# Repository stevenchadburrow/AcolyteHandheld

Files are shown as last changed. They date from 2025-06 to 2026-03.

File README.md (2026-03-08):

# Acolyte Handheld

The Acolyte Handheld is a portable PIC32MZ based game console, an revision of <a href="https://github.com/stevenchadburrow/AcolyteHandPICd32">my previous project</a>.  It is programmed with my own homebrew <a href="https://github.com/stevenchadburrow/PICnes">PICnes Emulator</a>, as well as the <a href="https://github.com/deltabeard/Peanut-GB">Peanut-GB Emulator</a> and the <a href="https://github.com/ITotalJustice/TotalSMS">TotalSMS Emulator</a>.  

<b>Features</b>

<ul>
  <li>Runs on a battery and is charged by a USB-C cable.</li>
  <li>Switchable between VGA and LCD displays without needing to reboot.</li>
  <li>Supports four players simultaneously through the use of additional controllers.</li>
  <li>The built-in NES emulator has been tested with over 120+ games at this point, including but not limited to the list <a href="https://github.com/stevenchadburrow/AcolyteHandPICd32/tree/main/NES">here</a>.  As a benchmark, Super Mario Bros 3 currently runs full speed at 30 FPS.  My demo video of Super Mario Bros 3 can be found <a href="https://www.youtube.com/watch?v=WGrEMQLWrP4">here</a>.</li>
  <li>The imported GB/GBC emulator is very accurate and runs games at full speed.</li>
  <li>The imported SMS/GG/SG emulator is very accurate and runs games at full speed.</li>
  <li>Built-in WAV audio player for listening to music.</li>
  <li>Custom built 3D printed enclosure and buttons.</li>
</ul>

<b>Specifications</b>

Microchip PIC32MZ2048EFH144 running at 300 MHz (overclocked)<br>
Internal memory of 512KB of RAM and 2MB of Flash ROM<br>
Added 4MB external SQI Flash ROM for GBC support<br>

<b>Video</b>

VGA 1024x768 resolution at 70 Hz with 256 colors or 65K colors<br>
ILI9341 LCD 320x240 resolution with 65K colors<br>
Effective resolution of NES emulator at 256x240, 3x integer scaled on VGA<br>
Effective resolution of GB/GBC/GG emulator at 160x144, 3x integer scaled on VGA<br>
Effective resolution of SMS/SG emulator at 256x192, 3x integer scaled on VGA<br>

<b>Audio</b>

Dual 6-bit audio channels<br>
Headphone jack and internal speaker<br>

<b>HID</b>

2x Sega Genesis controller ports<br>
USB port for keyboard, mouse, or Xbox-360 type controller<br>
14 mappable buttons on device<br>

<b>File System</b>

Elm-Chan's <a href="https://elm-chan.org/fsw/ff/">FatFS Generic FAT Filesystem Module</a> for Micro TF Cards<br>
(use command 'sudo mkfs.vfat /dev/sdX' to format card)<br>

<b>UART</b>

FT232RL USB-to-UART adapter<br>
(use command 'sudo picocom /dev/ttyUSB0' for default 9600 baud connection)<br>

<b>NES Emulator</b>

My own homebrew NES Emulator called <a href="my own homebrew NES emulator">PICnes</a>, supporting NROM, UxROM, CxROM, AxROM, MMC1, and MMC3 mappers<br>
Programmed with speed over accuracy in mind, runs most games at full speed without alteration<br>
Supports settings adjustments, game save files, and save-states<br>

<b>GB/GBC Emulator</b>

Mahyar Koshkouei's <a href="https://github.com/deltabeard/Peanut-GB">Peanut-GB (with MiniGB-APU) Emulator</a><br>
Copied and edited from the <a href="https://github.com/froggestspirit/Peanut-GB/">Version by "froggestspirit"</a> for GBC support<br>
Supports 1.5x scaling, DMG/GBC palettes, and game save files<br>

<b>SMS/GG/SG Emulator</b>

ITotalJustice's <a href="https://github.com/ITotalJustice/TotalSMS">TotalSMS Emulator</a><br>
Supports SMS / GG / SB games on same emulator, with game save files<br>

<b>WAV Audio Player</b>

Plays all tested .wav files with 1 or 2 channels, using 8 or 16 bits, and at any sample rate.<br>
(use 'ffmpeg' or 'sox' to convert your favorite .mp3 files to .wav format)<br>

<b>Links</b>

<a href="http://forum.6502.org/">http://forum.6502.org/</a> for the 6502 Forum, an incredible resource for everything 6502 related.<br>
<a href="https://www.nesdev.org/wiki/Nesdev_Wiki">https://www.nesdev.org/wiki/Nesdev_Wiki</a> for the very best NES programming guidance.<br> 
<a href="https://www.aidanmocke.com/">https://www.aidanmocke.com/</a> for a bunch of PIC32MZ projects (without Harmony), including USB.<br>
<a href="http://elm-chan.org/">http://elm-chan.org/</a> for a bunch of projects, including MMC (aka TF Card) and FatFs.<br>
<a href="https://github.com/deltabeard/">https://github.com/deltabeard/</a> for a bunch of projects, including Peanut-GB and MiniGB-APU projects.<br>
<a href="https://github.com/froggestspirit/">https://github.com/froggestspirit/</a> for a bunch of projects, including the GBC version of Peanut-GB.<br>
<a href="https://github.com/ITotalJustice/">https://github.com/ITotalJustice/</a> for a bunch of projects, including TotalSMS and other emulators.<br>
<a href="https://github.com/bfirsh/jsnes/tree/master/roms/lj65">https://github.com/bfirsh/jsnes/tree/master/roms/lj65</a> for LJ65 download and license (ROM in source).<br>
<a href="https://hackaday.com/2025/06/19/game-boy-nes-why-not-both/">https://hackaday.com/2025/06/19/game-boy-nes-why-not-both/</a> for the Hack-A-Day article!<br>

<b>Pictures</b>

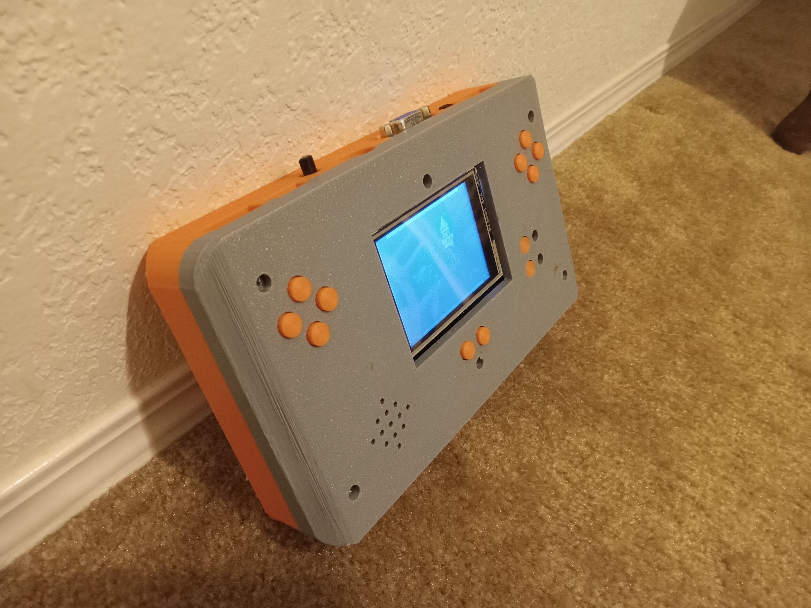
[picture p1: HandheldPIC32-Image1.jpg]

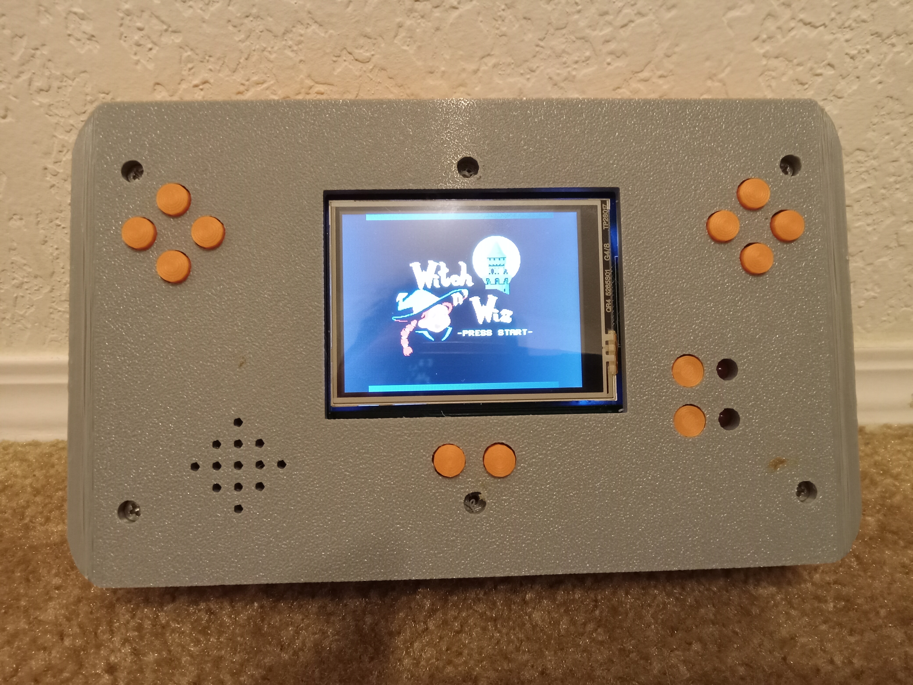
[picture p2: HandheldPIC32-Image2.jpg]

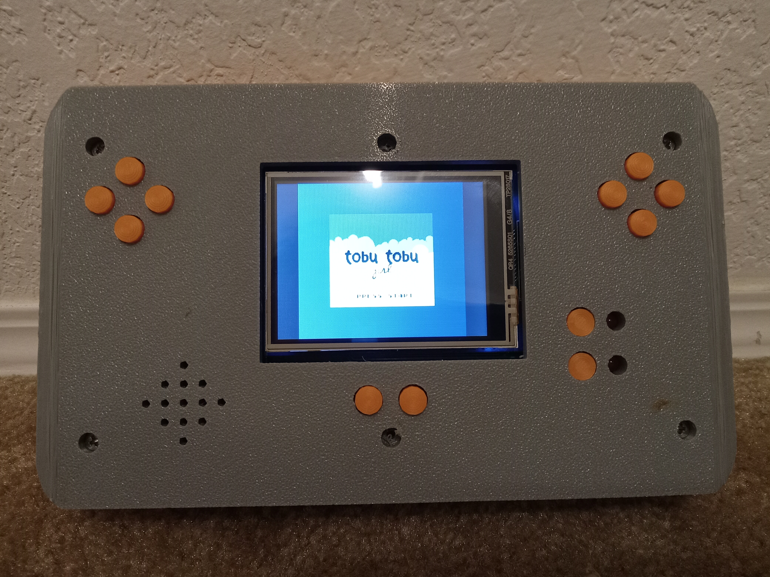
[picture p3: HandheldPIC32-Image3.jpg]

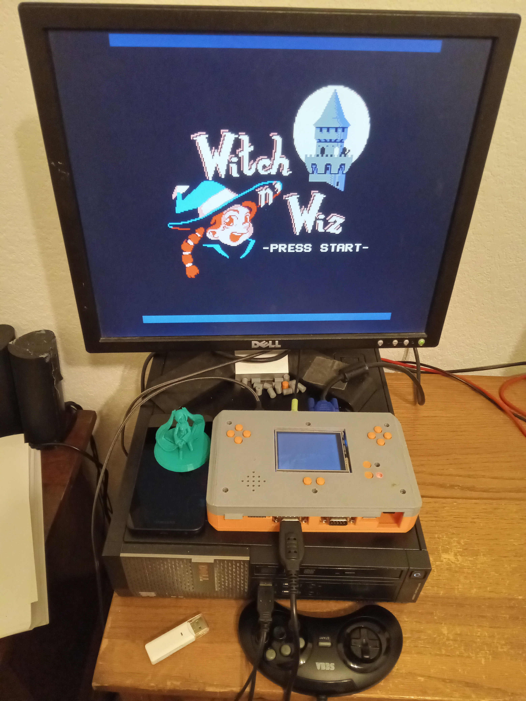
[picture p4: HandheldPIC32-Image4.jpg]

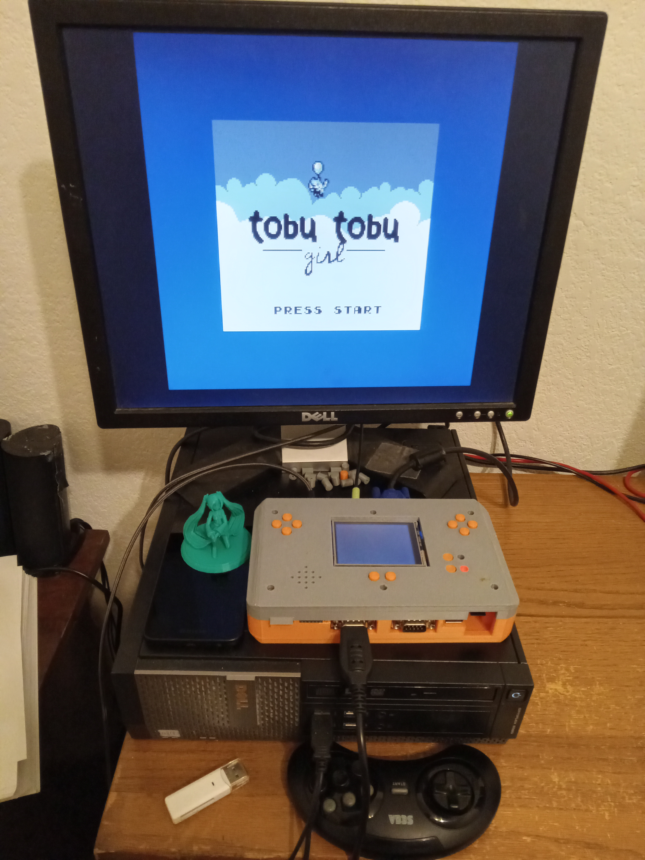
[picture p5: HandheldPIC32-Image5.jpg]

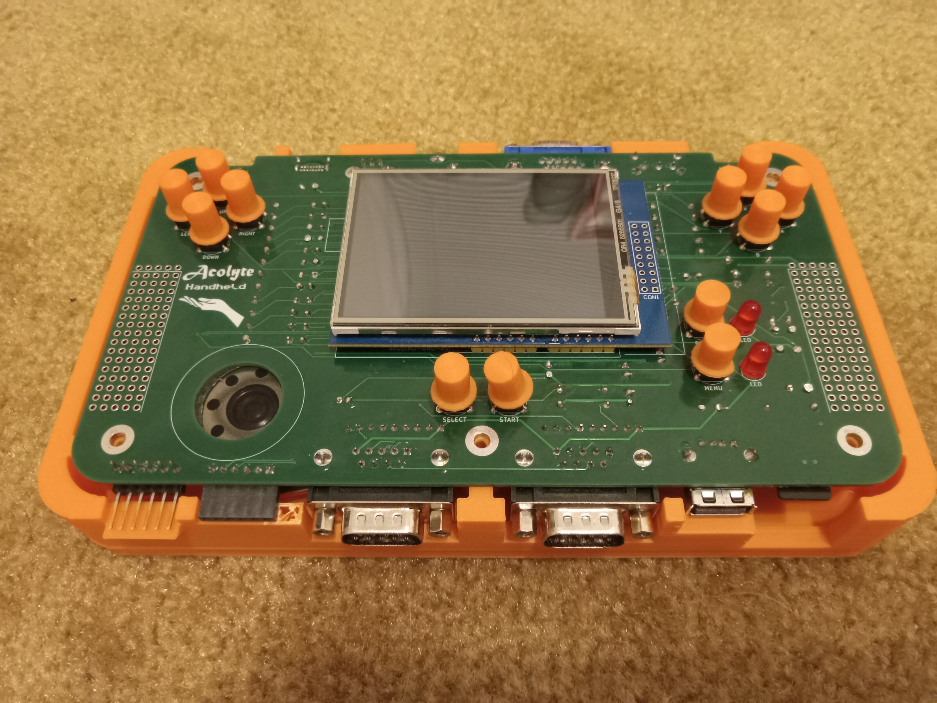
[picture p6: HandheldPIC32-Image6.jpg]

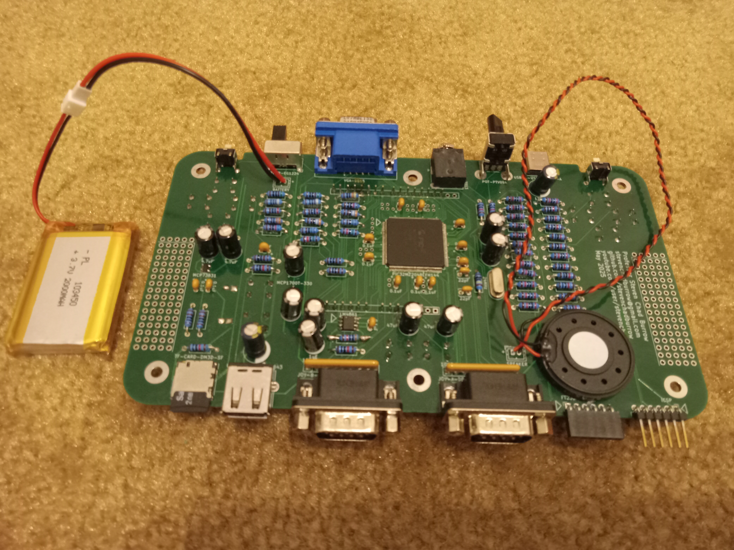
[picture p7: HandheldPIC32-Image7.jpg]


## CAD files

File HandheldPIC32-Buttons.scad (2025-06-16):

// typical buttons
translate([-10,0,0])
{
    difference()
    {
        intersection()
        {
            union()
            {
                cylinder(11,3.75,3.75,center=false);
                cylinder(0.75,5,5,center=false);
            }
            sphere(11);
        }
        cube([2.85,2.85,7],center=true);
       
    }
}

// reset and menu buttons
translate([10,0,0])
{
    difference()
    {
        difference()
        {
            union()
            {
                cylinder(9,3.75,3.75,center=false);
                difference()
                {
                    cylinder(0.75,5,5,center=false);
                    translate([3.75,-5,-1])
                    {
                        cube([10, 10, 10], center = false);
                    }
                }
            }
            translate([0,0,20])
            {
                sphere(12);
            }
        }
        cube([2.85,2.85,7],center=true);
       
    }
}

// no shoulder buttons yet!

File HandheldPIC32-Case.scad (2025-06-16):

h = 40; // total height of case
c = 15; // top height of the case

difference()
{
    translate([0, 0, c-h])
    {
        difference()
        {
            union()
            {
                // outside of case, good
                intersection()
                {
                    translate([-85, 45, 0])
                    { 
                        cylinder(h, 12, 12, center=false);
                    }
                    translate([-85, -57, h/2])
                    {
                        rotate([-90, 0, 0])
                        {
                            cylinder(114, h/2, h/2, center=false);
                        }
                    }
                }
                intersection()
                {
                    translate([-85, -45, 0])
                    { 
                        cylinder(h, 12, 12, center=false);
                    }
                    translate([-85, -57, h/2])
                    {
                        rotate([-90, 0, 0])
                        {
                            cylinder(114, h/2, h/2, center=false);
                        }
                    }
                }
                intersection()
                {
                    translate([85, 45, 0])
                    { 
                        cylinder(h, 12, 12, center=false);
                    }
                    translate([85, -57, h/2])
                    {
                        rotate([-90, 0, 0])
                        {
                            cylinder(114, h/2, h/2, center=false);
                        }
                    }
                }
                intersection()
                {
                    translate([85, -45, 0])
                    { 
                        cylinder(h, 12, 12, center=false);
                    }
                    translate([85, -57, h/2])
                    {
                        rotate([-90, 0, 0])
                        {
                            cylinder(114, h/2, h/2, center=false);
                        }
                    }
                }
                translate([-87, -57, 0])
                {
                    cube([174, 114, h], center=false);
                }
                intersection()
                {
                    translate([-97, -47, 0])
                    { 
                        cube([14, 94, h], center=false);
                    }
                    translate([-85, -55, h/2])
                    {
                        rotate([-90, 0, 0])
                        {
                            cylinder(114, h/2, h/2, center=false);
                        }
                    }
                }
                intersection()
                {
                    translate([83, -47, 0])
                    { 
                        cube([14, 94, h], center=false);
                    }
                    translate([85, -55, h/2])
                    {
                        rotate([-90, 0, 0])
                        {
                            cylinder(114, h/2, h/2, center=false);
                        }
                    }
                }
                difference() // programming pin protector, added
                {
                    translate([-80, -55, h-c-8.5])
                    {
                        rotate([45,0,0])
                        {
                            cube([16, 10, 10], center=false);
                        }
                    }
                    translate([-81, -100-40, h-c-3])
                    {
                        cube([18, 100, 3], center=false);
                    }
                }
            }
            union()
            {
                // inside of case, good
                translate([-80, 40, 5])
                { 
                    cylinder(h-10, 12, 12, center=false);
                }
                translate([-80, -40, 5])
                { 
                    cylinder(h-10, 12, 12, center=false);
                }
                translate([80, 40, 5])
                { 
                    cylinder(h-10, 12, 12, center=false);
                }
                translate([80, -40, 5])
                { 
                    cylinder(h-10, 12, 12, center=false);
                }
                translate([-82, -52, 5])
                {
                    cube([164, 104, h-10], center=false);
                }
                translate([-92, -42, 5])
                {
                    cube([14, 84, h-10], center=false);
                }
                translate([78, -42, 5])
                {
                    cube([14, 84, h-10], center=false);
                }
                
                // screw holes, good
                translate([-80, 40, h-5])
                {
                    cylinder(20, 3, 3, center=false);
                }
                translate([-80, -40, h-5])
                {
                    cylinder(20, 3, 3, center=false);
                }
                translate([0, 40, h-5])
                {
                    cylinder(20, 3, 3, center=false);
                }
                translate([0, -40, h-5])
                {
                    cylinder(20, 3, 3, center=false);
                }
                translate([80, 40, h-5])
                {
                    cylinder(20, 3, 3, center=false);
                }
                translate([80, -40, h-5])
                {
                    cylinder(20, 3, 3, center=false);
                }
                
                // button holes, good
                translate([-70, 33, h-c])
                {
                    cylinder(100, 4.25, 4.25, center=false);
                }
                translate([-78, 25, h-c])
                {
                    cylinder(100, 4.25, 4.25, center=false);
                }
                translate([-70, 17, h-c])
                {
                    cylinder(100, 4.25, 4.25, center=false);
                }
                translate([-62, 25, h-c])
                {
                    cylinder(100, 4.25, 4.25, center=false);
                }
                translate([70, 33, h-c])
                {
                    cylinder(100, 4.25, 4.25, center=false);
                }
                translate([78, 25, h-c])
                {
                    cylinder(100, 4.25, 4.25, center=false);
                }
                translate([70, 17, h-c])
                {
                    cylinder(100, 4.25, 4.25, center=false);
                }
                translate([62, 25, h-c])
                {
                    cylinder(100, 4.25, 4.25, center=false);
                }
                translate([-6, -30, h-c])
                {
                    cylinder(100, 4.25, 4.25, center=false);
                }
                translate([6, -30, h-c])
                {
                    cylinder(100, 4.25, 4.25, center=false);
                }
                translate([52, -10, h-c])
                {
                    cylinder(100, 4.25, 4.25, center=false);
                }
                translate([52, -22, h-c])
                {
                    cylinder(100, 4.25, 4.25, center=false);
                }
                
                // led holes, good
                translate([61.735, -10, h-c])
                {
                    cylinder(100, 3, 3, center=false);
                }
                translate([61.735, -22, h-c])
                {
                    cylinder(100, 3, 3, center=false);
                }
                
                // shoulder button holes, fixed
                translate([-75, 39.25, h-c-9])
                {
                    cube([10, 7.5, 10], center=false);
                }
                translate([-70-10, 39.25, h-c-9])
                {
                    cube([20, 20, c-5], center=false);
                }
                translate([65, 39.25, h-c-9])
                {
                    cube([10, 7.5, 10], center=false);
                }
                translate([70-10, 39.25, h-c-9])
                {
                    cube([20, 20, c-5], center=false);
                }
                
                // screen hole, fixed
                translate([-35, -20, h-c])
                {
                    cube([72, 55, 100], center=false);
                }
                
                // speaker holes, good
                translate([-55, -30, h-c])
                {
                    cylinder(7.5, 15, 15, center=false);
                    cylinder(100, 1.5, 1.5, center=false);
                }
                translate([-60, -30, h-c])
                {
                    cylinder(100, 1.5, 1.5, center=false);
                }
                translate([-50, -30, h-c])
                {
                    cylinder(100, 1.5, 1.5, center=false);
                }
                translate([-55, -25, h-c])
                {
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

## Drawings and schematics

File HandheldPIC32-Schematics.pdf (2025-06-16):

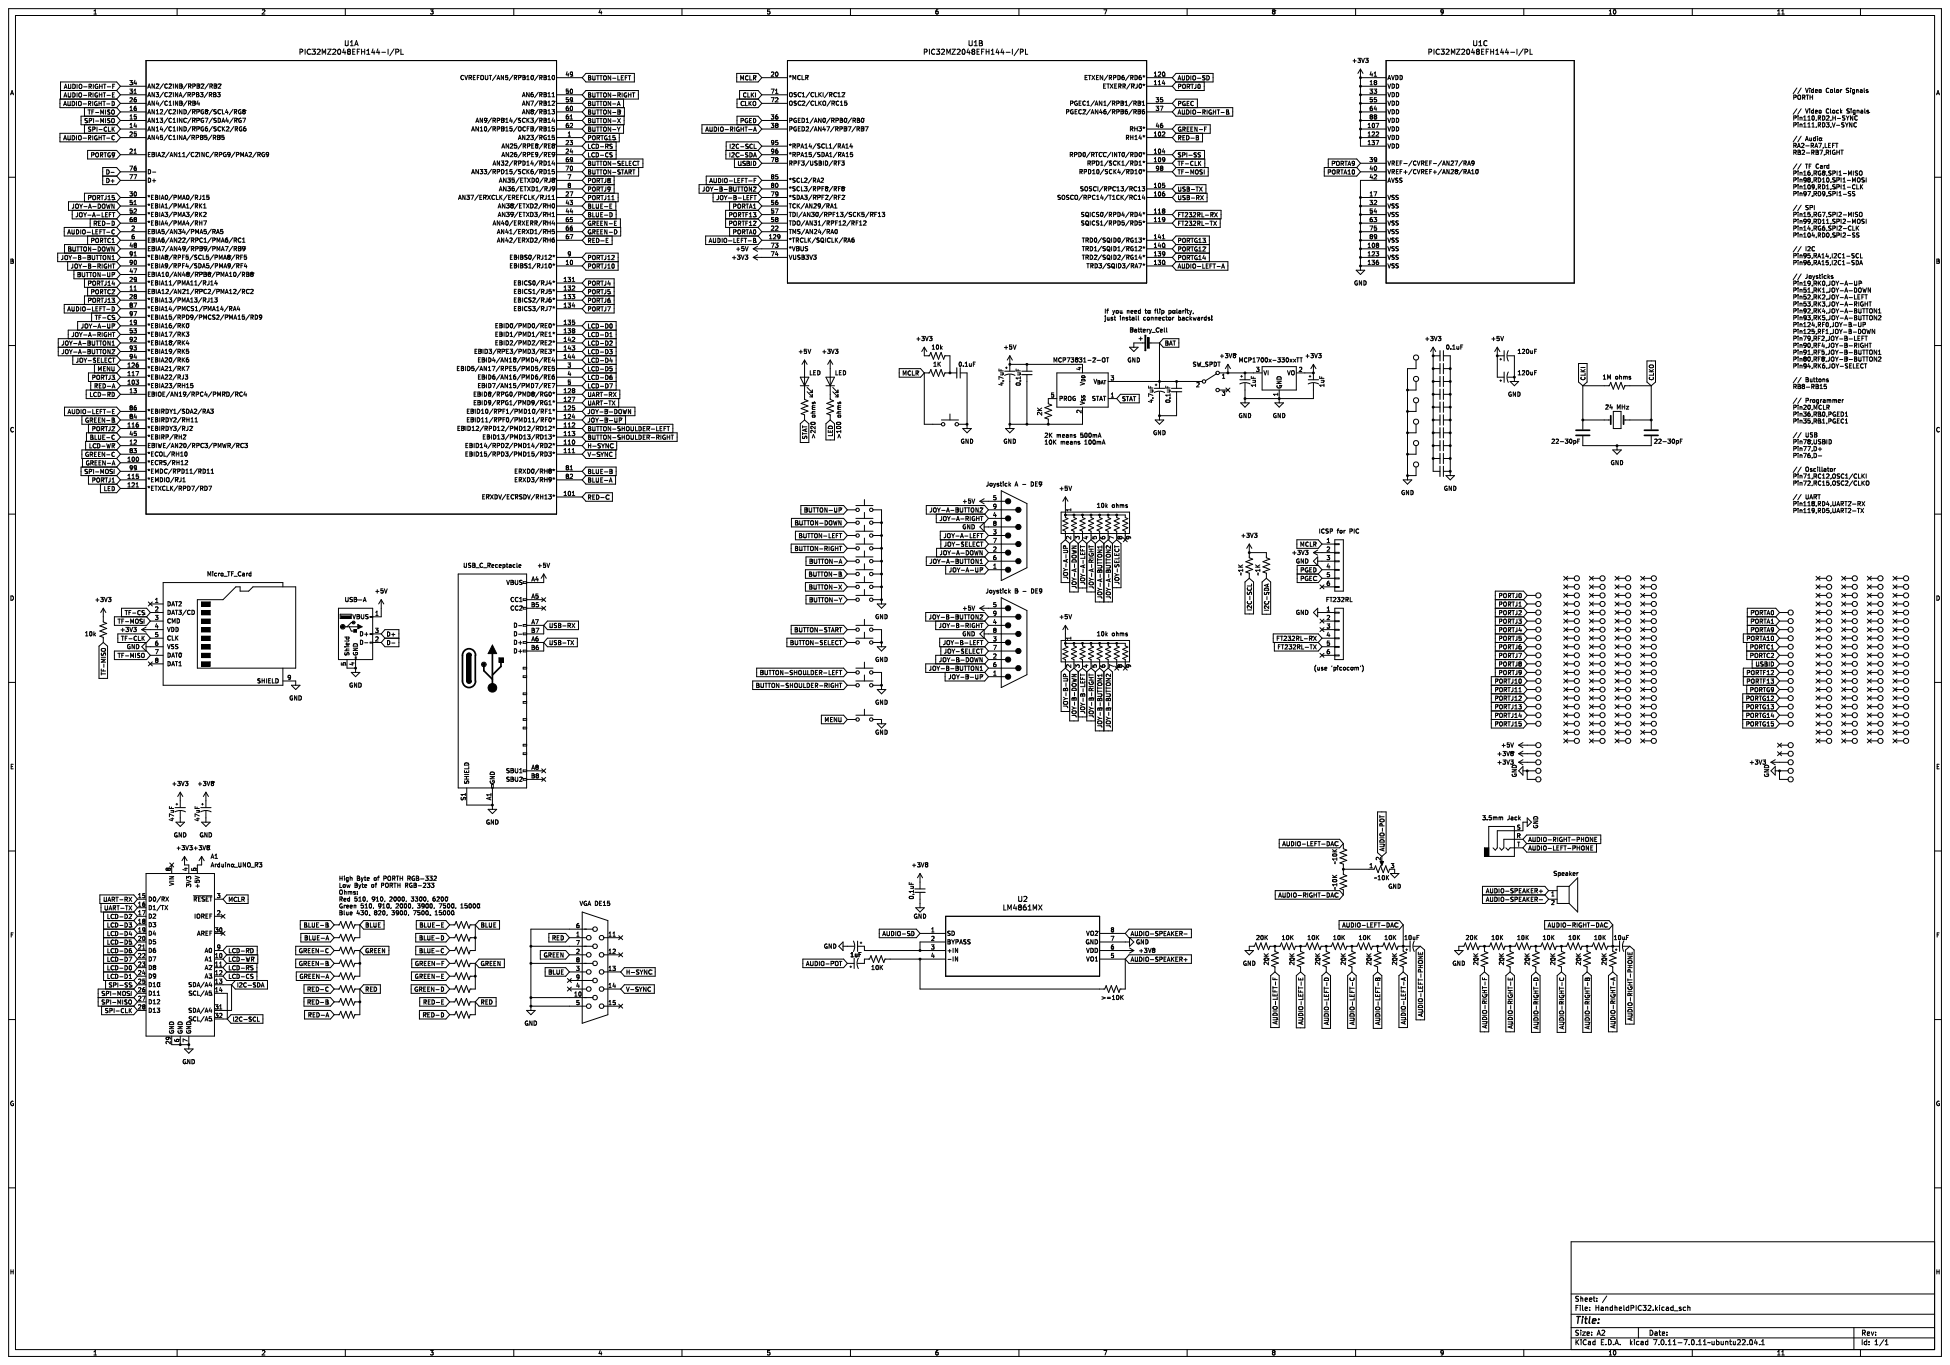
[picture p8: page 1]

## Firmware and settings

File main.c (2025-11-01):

// Handheld PIC 32
// By: Professor Steven Chad Burrow



/*
XGA Signal 1024 x 768 @ 60 Hz timing

Interested in easy to use VGA solution for embedded applications? Click here!

General timing
Screen refresh rate	60 Hz
Vertical refresh	48.363095238095 kHz
Pixel freq.	65.0 MHz
Horizontal timing (line)
Polarity of horizontal sync pulse is negative.

Scanline part	Pixels	Time [µs]
Visible area	1024	15.753846153846
Front porch	24	0.36923076923077
Sync pulse	136	2.0923076923077
Back porch	160	2.4615384615385
Whole line	1344	20.676923076923
Vertical timing (frame)
Polarity of vertical sync pulse is negative.

Frame part	Lines	Time [ms]
Visible area	768	15.879876923077
Front porch	3	0.062030769230769
Sync pulse	6	0.12406153846154
Back porch	29	0.59963076923077
Whole frame	806	16.6656
*/

/*
VESA Signal 1024 x 768 @ 70 Hz timing

General timing
Screen refresh rate	70 Hz
Vertical refresh	56.475903614458 kHz
Pixel freq.	75.0 MHz
Horizontal timing (line)
Polarity of horizontal sync pulse is negative.

Scanline part	Pixels	Time [µs]
Visible area	1024	13.653333333333
Front porch	24	0.32
Sync pulse	136	1.8133333333333
Back porch	144	1.92
Whole line	1328	17.706666666667
Vertical timing (frame)
Polarity of vertical sync pulse is negative.

Frame part	Lines	Time [ms]
Visible area	768	13.59872
Front porch	3	0.05312
Sync pulse	6	0.10624
Back porch	29	0.51349333333333
Whole frame	806	14.271573333333 
*/

/*
// Video Color Signals
PORTH

// Video Clock Signals
Pin110,RD2,H-SYNC
Pin111,RD3,V-SYNC

// Audio
RA2-RA7,LEFT
RB2-RB7,RIGHT

// TF Card
Pin16,RG8,SPI1-MISO
Pin98,RD10,SPI1-MOSI
Pin109,RD1,SPI1-CLK
Pin97,RD9,SPI1-SS

// SPI
Pin15,RG7,SPI2-MISO
Pin99,RD11,SPI2-MOSI
Pin14,RG6,SPI2-CLK
Pin104,RD0,SPI2-SS

// I2C
Pin95,RA14,I2C1-SCL
Pin96,RA15,I2C1-SDA

// Joysticks
Pin19,RK0,JOY-A-UP
Pin51,RK1,JOY-A-DOWN
Pin52,RK2,JOY-A-LEFT
Pin53,RK3,JOY-A-RIGHT
Pin92,RK4,JOY-A-BUTTON1
Pin93,RK5,JOY-A-BUTTON2
Pin124,RF0,JOY-B-UP
Pin125,RF1,JOY-B-DOWN
Pin79,RF2,JOY-B-LEFT
Pin90,RF4,JOY-B-RIGHT
Pin91,RF5,JOY-B-BUTTON1
Pin80,RF8,JOY-B-BUTTON2
Pin94,RK6,JOY-SELECT

// Buttons
RB8-RB15

// Programmer
Pin20,MCLR
Pin36,RB0,PGED1
Pin35,RB1,PGEC1

// USB
Pin78,USBID
Pin77,D+
Pin76,D-

// Oscillator
Pin71,RC12,OSC1/CLKI
Pin72,RC15,OSC2/CLKO

// UART
Pin118,RD4,UART2-RX
Pin119,RD5,UART2-TX
*/

/*
RA0	
RA1	
RA2	AUDIO-LEFT-F
RA3	AUDIO-LEFT-E
RA4	AUDIO-LEFT-D
RA5	AUDIO-LEFT-C
RA6	AUDIO-LEFT-B
RA7	AUDIO-LEFT-A
----	
RA9	
RA10	
----	
----	
----	
RA14	I2C-SCL
RA15	I2C-SDA
RB0	PGED
RB1	PGEC
RB2	AUDIO-RIGHT-F
RB3	AUDIO-RIGHT-E
RB4	AUDIO-RIGHT-D
RB5	AUDIO-RIGHT-C
RB6	AUDIO-RIGHT-B
RB7	AUDIO-RIGHT-A
RB8	BUTTON-UP
RB9	BUTTON-DOWN
RB10	BUTTON-LEFT
RB11	BUTTON-RIGHT
RB12	BUTTON-A
RB13	BUTTON-B
RB14	BUTTON-X
RB15	BUTTON-Y
----	
RC1	
RC2	
RC3	LCD-WR
RC4	LCD-RD
----	
----	
----	
----	
----	
----	
----	
RC12	CLKI
RC13	USB-TX
RC14	USB-RX
RC15	CLKO
RD0	SPI-SS
RD1	TF-CLK
RD2	H-SYNC
RD3	V-SYNC
RD4	FT232RL-RX
RD5	FT232RL-TX
RD6	AUDIO-SD
RD7	LED
----	
RD9	TF-CS
RD10	TF-MOSI
RD11	SPI-MOSI
RD12	SHOULDER-LEFT
RD13	SHOULDER-RIGHT
RD14	BUTTON-SELECT
RD15	BUTTON-START
RE0	LCD-D0
RE1	LCD-D1
RE2	LCD-D2
RE3	LCD-D3
RE4	LCD-D4
RE5	LCD-D5
RE6	LCD-D6
RE7	LCD-D7
RE8	LCD-RS
RE9	LCD-CS
----	
----	
----	
----	
----	
----	
RF0	JOY-B-UP
RF1	JOY-B-DOWN
RF2	JOY-B-LEFT
RF3	USBID
RF4	JOY-B-RIGHT
RF5	JOY-B-BUTTON1
----	
----	
RF8	JOY-B-BUTTON2
----	
----	
----	
RF12	
RF13	
----	
----	
RG0	UART-RX
RG1	UART-TX
----	
----	
----	
----	
RG6	SPI-CLK
RG7	SPI-MISO
RG8	TF-MISO
RG9	
----	
----	
RG12	
RG13	
RG14	
RG15	
RH0	BLUE-E
RH1	BLUE-D
RH2	BLUE-C
RH3	GREEN-F
RH4	GREEN-E
RH5	GREEN-D
RH6	RED-E
RH7	RED-D
RH8	BLUE-B
RH9	BLUE-A
RH10	GREEN-C
RH11	GREEN-B
RH12	GREEN-A
RH13	RED-C
RH14	RED-B
RH15	RED-A
RJ0	PORTJ0
RJ1	PORTJ1
RJ2	PORTJ2
RJ3	PORTJ3
RJ4	PORTJ4
RJ5	PORTJ5
RJ6	PORTJ6
RJ7	PORTJ7
RJ8	PORTJ8
RJ9	PORTJ9
RJ10	PORTJ10
RJ11	PORTJ11
RJ12	PORTJ12
RJ13	PORTJ13
RJ14	PORTJ14
RJ15	PORTJ15
RK0	JOY-A-UP
RK1	JOY-A-DOWN
RK2	JOY-A-LEFT
RK3	JOY-A-RIGHT
RK4	JOY-A-BUTTON1
RK5	JOY-A-BUTTON2
RK6	JOY-SELECT
RK7	MENU
----	
----	
----	
----	
----	
----	
----	
----	

 
*/


// By the way, to convert .mp4 to .gif:
// ffmpeg -i input.mp4 -vf scale=320:-1 -r 10 -f image2pipe -vcodec ppm - | convert -delay 10 -loop 0 - output.gif


// When connecting with the UART, use:
// sudo picocom /dev/ttyUSB0


// PIC32MZ2048EFM144 Configuration Bit Settings

// 'C' source line config statements

// DEVCFG3
#pragma config USERID = 0xFFFF          // Enter Hexadecimal value (Enter Hexadecimal value)
#pragma config FMIIEN = ON              // Ethernet RMII/MII Enable (MII Enabled)
#pragma config FETHIO = OFF             // Ethernet I/O Pin Select (Alternate Ethernet I/O)
#pragma config PGL1WAY = OFF            // Permission Group Lock One Way Configuration (Allow multiple reconfigurations)
#pragma config PMDL1WAY = OFF           // Peripheral Module Disable Configuration (Allow multiple reconfigurations)
#pragma config IOL1WAY = OFF            // Peripheral Pin Select Configuration (Allow multiple reconfigurations)
#pragma config FUSBIDIO = OFF           // USB USBID Selection (Controlled by Port Function)

// DEVCFG2
#pragma config FPLLIDIV = DIV_3         // System PLL Input Divider (3x Divider)
#pragma config FPLLRNG = RANGE_5_10_MHZ// System PLL Input Range (5-10 MHz Input)
#pragma config FPLLICLK = PLL_POSC       // System PLL Input Clock Selection (FRC is input to the System PLL)
#pragma config FPLLMULT = MUL_50       // System PLL Multiplier (PLL Multiply by 50)
#pragma config FPLLODIV = DIV_2         // System PLL Output Clock Divider (2x Divider)
#pragma config UPLLFSEL = FREQ_24MHZ    // USB PLL Input Frequency Selection (USB PLL input is 24 MHz)

// DEVCFG1
#pragma config FNOSC = FRCDIV           // Oscillator Selection Bits (Fast RC Osc w/Div-by-N (FRCDIV))
#pragma config DMTINTV = WIN_127_128    // DMT Count Window Interval (Window/Interval value is 127/128 counter value)
#pragma config FSOSCEN = OFF            // Secondary Oscillator Enable (Disable SOSC)
#pragma config IESO = ON                // Internal/External Switch Over (Enabled)
#pragma config POSCMOD = HS             // Primary Oscillator Configuration (HS osc mode)
#pragma config OSCIOFNC = ON            // CLKO Output Signal Active on the OSCO Pin (Enabled)
#pragma config FCKSM = CSECME           // Clock Switching and Monitor Selection (Clock Switch Enabled, FSCM Enabled)
#pragma config WDTPS = PS1048576        // Watchdog Timer Postscaler (1:1048576)
#pragma config WDTSPGM = STOP           // Watchdog Timer Stop During Flash Programming (WDT stops during Flash programming)
#pragma config WINDIS = NORMAL          // Watchdog Timer Window Mode (Watchdog Timer is in non-Window mode)
#pragma config FWDTEN = OFF             // Watchdog Timer Enable (WDT Disabled)
#pragma config FWDTWINSZ = WINSZ_50     // Watchdog Timer Window Size (Window size is 50%)
#pragma config DMTCNT = DMT31           // Deadman Timer Count Selection (2^31 (2147483648))
#pragma config FDMTEN = OFF             // Deadman Timer Enable (Deadman Timer is disabled)

// DEVCFG0
#pragma config DEBUG = OFF              // Background Debugger Enable (Debugger is disabled)
#pragma config JTAGEN = OFF             // JTAG Enable (JTAG Disabled)
#pragma config ICESEL = ICS_PGx1        // ICE/ICD Comm Channel Select (Communicate on PGEC1/PGED1)
#pragma config TRCEN = OFF               // Trace Disable (Trace features in the CPU are disabled)
#pragma config BOOTISA = MIPS32         // Boot ISA Selection (Boot code and Exception code is MIPS32)
#pragma config FECCCON = OFF_UNLOCKED   // Dynamic Flash ECC Configuration (ECC and Dynamic ECC are disabled (ECCCON bits are writable))
//#pragma config FECCCON = ON             // Dynamic Flash ECC Configuration (Flash ECC is enabled (ECCCON bits are locked))
#pragma config FSLEEP = VREGS           // Flash Sleep Mode (Flash power down is controlled by the VREGS bit)
#pragma config DBGPER = PG_ALL          // Debug Mode CPU Access Permission (Allow CPU access to all permission regions)
#pragma config SMCLR = MCLR_NORM        // Soft Master Clear Enable bit (MCLR pin generates a normal system Reset)
#pragma config SOSCGAIN = GAIN_2X       // Secondary Oscillator Gain Control bits (2x gain setting)
#pragma config SOSCBOOST = OFF          // Secondary Oscillator Boost Kick Start Enable bit (Normal start of the oscillator)
#pragma config POSCGAIN = GAIN_2X       // Primary Oscillator Gain Control bits (2x gain setting)
#pragma config POSCBOOST = OFF          // Primary Oscillator Boost Kick Start Enable bit (Normal start of the oscillator)
#pragma config EJTAGBEN = NORMAL        // EJTAG Boot (Normal EJTAG functionality)

// DEVCP0
#pragma config CP = OFF                 // Code Protect (Protection Disabled)

// SEQ3
#pragma config TSEQ = 0xFFFF            // Boot Flash True Sequence Number (Enter Hexadecimal value)
#pragma config CSEQ = 0xFFFF            // Boot Flash Complement Sequence Number (Enter Hexadecimal value)

// #pragma config statements should precede project file includes.
// Use project enums instead of #define for ON and OFF.

#include <xc.h>

#define SYS_FREQ 300000000 // Running at 300MHz

// keeps program code from being written here, reserved for NES
#pragma region name="cart_rom" origin=0x9D100000 size=0x00100000 // for NES and GB
#pragma region name="game_rom" origin=0x9D0F0000 size=0x00010000 // pack-in game


unsigned long VirtToPhys(volatile void* p) // changed 'const' to 'volatile'
{
	return (long)p<0?((long)p&0x1fffffffL):(unsigned long)((unsigned long*)p+0x40000000L);
}

void DelayMS(unsigned int s)
{
	unsigned long count = 0x00000000;
	
	count = (unsigned long)((unsigned long)((SYS_FREQ / 1000) * s) / 2); // Convert microseconds us into how many clock ticks it will take
       
	_CP0_SET_COUNT(0); // Set Core Timer count to 0
    
	while (count > _CP0_GET_COUNT()); // Wait until Core Timer count reaches the number we calculated earlier
}

// if using UART, use command 'sudo picocom /dev/ttyUSB0' in Linux
void SendChar(char value)
{
	char temp = value;
	while (U2STAbits.UTXBF == 1) { }
	U2TXREG = (char)(temp);
}

void SendString(char *value)
{
	char temp;
	for (unsigned int i=0; i<256; i++)
	{
		temp = value[i];
		
		if (temp == '\\') break;
		else
		{
			while (U2STAbits.UTXBF == 1) { }
			U2TXREG = (char)(temp);
		}
	}
}

void SendHex(unsigned char value)
{
	unsigned char temp = value;
	while (U2STAbits.UTXBF == 1) { }
	if (temp/16 >= 10) U2TXREG = (char)(temp/16 + 'A' - 10);
	else U2TXREG = (char)(temp/16 + '0');
	while (U2STAbits.UTXBF == 1) { }
	if (temp%16 >= 10) U2TXREG = (char)(temp%16 + 'A' - 10);
	else U2TXREG = (char)(temp%16 + '0');
}

void SendLongHex(unsigned long value)
{
	unsigned long temp = value;
	SendHex((unsigned char)(temp >> 24));
	SendHex((unsigned char)(temp >> 16));
	SendHex((unsigned char)(temp >> 8));
	SendHex((unsigned char)(temp));
}

volatile unsigned long debug_opcode = 0x0000;
volatile unsigned long debug_operand_1 = 0x0000;
volatile unsigned long debug_operand_2 = 0x0000;
volatile unsigned long debug_location = 0x0000; // TEMPORARY!
volatile unsigned long debug_value = 0x0000; // TEMPORARY!

void _general_exception_handler(void)
{	
	SendString("General Exception\n\r\\");
	SendLongHex(((_CP0_GET_CAUSE() & 0x0000007C) >> 2));
	SendString("\n\r\\");
    SendLongHex(_CP0_GET_EPC());
	SendString("\n\r\\");
	SendLongHex(INTSTAT);
	SendString("\n\r\\");
	
	SendString("Debug Opcode \\");
	SendLongHex(debug_opcode); // TEMPORARY!
	SendString("\n\r\\");
	
	SendString("Debug Operand 1 \\");
	SendLongHex(debug_operand_1); // TEMPORARY!
	SendString("\n\r\\");
	
	SendString("Debug Operand 2 \\");
	SendLongHex(debug_operand_2); // TEMPORARY!
	SendString("\n\r\\");
	
	SendString("Debug Location \\");
	SendLongHex(debug_location); // TEMPORARY!
	SendString("\n\r\\");
	
	SendString("Debug Value \\");
	SendLongHex(debug_value); // TEMPORARY!
	SendString("\n\r\\");
	
	DelayMS(1000);
	
	// soft reset system
	SYSKEY = 0x0; // reset
	SYSKEY = 0xAA996655; // unlock key #1
	SYSKEY = 0x556699AA; // unlock key #2
	RSWRST = 1; // set bit to reset of system
	SYSKEY = 0x0; // re-lock
	RSWRST; // read from register to reset
	while (1) { } // wait until reset occurs
}



//#define DEBUG // uncomment to send debug info through UART

#ifdef DEBUG
unsigned long debug_counter[8];
unsigned long debug_frames = 0;

void debug_reset()
{
	_CP0_SET_COUNT(0);
}

void debug_capture(unsigned char i)
{
	debug_counter[i] += _CP0_GET_COUNT();
}

void debug_report()
{
	debug_frames++;
		
	if (debug_frames >= 60) // once per second
	{
		debug_frames = 0;

		for (unsigned char i=0; i<8; i++)
		{
			SendLongHex(debug_counter[i]);
			DelayMS(10);
			SendChar('.');
			DelayMS(1);

			debug_counter[i] = 0;
		}
		
		SendChar('\n');
		DelayMS(1);
		SendChar('\r');
		DelayMS(1);
	}
}	
#endif



volatile unsigned char *cart_rom = (volatile unsigned char *)0x9D100000;
volatile unsigned char sys_ram[8192]; // used for NES and SMS
volatile unsigned char cart_ram[32768]; // used for NES, GB, and SMS
volatile unsigned char ext_ram[32768]; // used for NES, GB, and SMS (and WAV music)

volatile unsigned long interrupt_count = 0; // used for frame timing


#define SCREEN_X 768
#define SCREEN_X2 1536
#define SCREEN_Y 240
#define SCREEN_Y2 480
#define SCREEN_HXY 92160
#define SCREEN_XY 184320
#define SCREEN_XY2 368640
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
int main()
{	
	unsigned short menu_pos = 0;
	unsigned long menu_wait = 0;
	unsigned long menu_delay = 0;
	
	audio_enable = 0;
	controller_enable = 1;
	screen_frame = 0;
	screen_menu = 1;
	
	Setup();
	Display();
	
	screen_clear();
	audio_clear();
	
	PORTDbits.RD7 = 0; // turn on LED
	
	DelayMS(100);
	DelayMS(100);
	DelayMS(100);
	DelayMS(100);
	DelayMS(100);

	USBHostSetup();
	
	DelayMS(100);
	DelayMS(100);
	DelayMS(100);
	DelayMS(100);
	DelayMS(100);
	
	// if menu button held down during boot, start in VGA
	//if ((!PORTKbits.RK7)) screen_handheld = 0;
	//else screen_handheld = 1;
	
	// if controllers detected, start in VGA
	//if (controller_detect_1 > 0 || controller_detect_2 > 0) screen_handheld = 0;
	
	// if USB device detected, start in VGA
	//if (usbhost_connected > 0) screen_handheld = 0;
	
	// VGA detect pin
	if (PORTAbits.RA0 == 0) screen_handheld = 0;
	else screen_handheld = 1;
	
	/*
	// initialize SQI chip
	if (sqi_initialize() == 0)
	{
		//SendString("SQI Not Initialized!\n\r\\");
	}
	*/
	
	screen_clear();
	audio_clear();
	
	lcd_init();
	
	DelayMS(100);
	DelayMS(100);
	DelayMS(100);
	DelayMS(100);
	DelayMS(100);
	
	SendChar('$'); // just a 'hello world' over the UART
	
	DelayMS(100);
	DelayMS(100);
	DelayMS(100);
	DelayMS(100);
	DelayMS(100);
	
	PORTDbits.RD7 = 1; // turn off LED
	
	audio_enable = 0;
	controller_enable = 1;
	screen_frame = 0;
	screen_menu = 1;
	
	unsigned short sdcard_flag = 0;
	
	//SendString("Checking TF Card...\n\r\\");
	
	// Wait for the disk to initialise
    if (disk_initialize(0) == 0)
	{
		sdcard_flag = 1;
	}
	
	//SendString("TF Card Found!\n\r\\");
	
	// root directory
	directory_name[0] = '/';
	directory_name[1] = 0;
	directory_name[2] = 0;
	directory_name[3] = 0;
	directory_name[4] = 0;
	directory_name[5] = 0;
	directory_name[6] = 0;
	directory_name[7] = 0;
	directory_name[8] = 0;
	directory_name[9] = 0;
	directory_name[10] = 0;
	directory_name[11] = 0;
	
	directory_root = 1; // root
	
	while (1)
	{
		while ((controller_status_1 & 0x0F) != 0x00 || 
			(controller_status_2 & 0x0F) != 0x00 ||
			(controller_status_3 & 0x0F) != 0x00 || 
			(controller_status_4 & 0x0F) != 0x00)
		{
			USBHostTasks();
		}
		
		DelayMS(100);
		DelayMS(100);
		DelayMS(100);
		DelayMS(100);
		DelayMS(100);
		
		list_total = 1; // start at 1
		
		list_generate(sdcard_flag);

		if (list_total == 1) // in case of a blank folder
		{
			// root directory
			directory_name[0] = '/';
			directory_name[1] = 0;
			directory_name[2] = 0;
			directory_name[3] = 0;
			directory_name[4] = 0;
			directory_name[5] = 0;
			directory_name[6] = 0;
			directory_name[7] = 0;
			directory_name[8] = 0;
			directory_name[9] = 0;
			directory_name[10] = 0;
			directory_name[11] = 0;
			
			directory_root = 1;
			
			list_generate(sdcard_flag);
		}
		
		menu_pos = 0;
		menu_wait = 0x0007FFFF;

		list_display(menu_pos);
		screen_flip();

		//list_picture(menu_pos);
		
		while (((controller_status_1 & 0x0F) == 0x00 && 
			(controller_status_2 & 0x0F) == 0x00 &&
			(controller_status_3 & 0x0F) == 0x00 && 
			(controller_status_4 & 0x0F) == 0x00) ||
			menu_wait > 0)
		{			
			USBHostTasks();

			if (screen_redraw > 0)
			{
				screen_redraw = 0;

				list_display(menu_pos);
				screen_flip();
			}

			if (((controller_status_1 & 0x10) == 0x10 ||
				(controller_status_2 & 0x10) == 0x10 ||
				(controller_status_3 & 0x10) == 0x10 ||
				(controller_status_4 & 0x10) == 0x10) &&
				menu_wait == 0)
			{
				menu_wait = 0x0007FFFF;

				if (menu_pos > 0) menu_pos--;

				list_display(menu_pos);
				screen_flip();

				//for (unsigned int i=0; i<240; i++)
				//{
				//	for (unsigned int j=0; j<384; j++)
				//	{
				//		screen_buffer[(240-i)*SCREEN_X + 256 + j] = 0x00;
				//	}
				//}
			}
			else
			{
				if (menu_wait > 0) menu_wait--;
			}

			if (((controller_status_1 & 0x20) == 0x20 ||
				(controller_status_2 & 0x20) == 0x20 ||
				(controller_status_3 & 0x20) == 0x20 ||
				(controller_status_4 & 0x20) == 0x20) && 
				menu_wait == 0)
			{
				menu_wait = 0x0007FFFF;

				if (menu_pos < list_total-1) menu_pos++;

				list_display(menu_pos);
				screen_flip();

				//for (unsigned int i=0; i<240; i++)
				//{
				//	for (unsigned int j=0; j<384; j++)
				//	{
				//		screen_buffer[(240-i)*SCREEN_X + 256 + j] = 0x00;
				//	}
				//}
			}
			else
			{
				if (menu_wait > 0) menu_wait--;
			}

			if (menu_wait == 0)
			{
				if (menu_delay > 0) menu_delay--;

				if (menu_delay == 1)
				{
					//list_picture(menu_pos);
				}
			}
			else
			{
				menu_delay = 0x000BFFFF;
			}
		}

		screen_clear();
		audio_clear();
		
		DelayMS(100);
		DelayMS(100);
		DelayMS(100);
		DelayMS(100);
		DelayMS(100);

		if ((menu_pos == 0 || menu_pos == 1) && directory_root == 1) // play game!
		{		
			audio_enable = 1; // audio on by default
			controller_enable = 1; // must be on to play games

			if (menu_pos == 1)
			{
				cart_rom = (volatile unsigned char *)0x9D0F0000; // change cart_rom to pack-in-game
			}
			
			menu_hold = 0;
			
			if (PORTKbits.RK7 == 0) // holding menu button
			{
				menu_function();
				
				menu_hold = 1;
			}
			
			if ((controller_status_1 & 0x10) == 0x10 ||
				(controller_status_2 & 0x10) == 0x10 ||
				(controller_status_3 & 0x10) == 0x10 ||
				(controller_status_4 & 0x10) == 0x10) // UP, GB override
			{
				game_loop(2);
			}
			else if (((controller_status_1 & 0x40) == 0x40 ||
				(controller_status_2 & 0x40) == 0x40 ||
				(controller_status_3 & 0x40) == 0x40 ||
				(controller_status_4 & 0x40) == 0x40) &&
				((controller_status_1 & 0x40) == 0x40 ||
				(controller_status_2 & 0x40) == 0x40 ||
				(controller_status_3 & 0x40) == 0x40 ||
				(controller_status_4 & 0x40) == 0x40)) // both LEFT and RIGHT, GBC with SQI
			{				
				game_loop(6);
			}
			else if ((controller_status_1 & 0x40) == 0x40 ||
				(controller_status_2 & 0x40) == 0x40 ||
				(controller_status_3 & 0x40) == 0x40 ||
				(controller_status_4 & 0x40) == 0x40) // LEFT, SMS override
			{
				game_loop(4);
			}
			else if ((controller_status_1 & 0x80) == 0x80 ||
				(controller_status_2 & 0x80) == 0x80 ||
				(controller_status_3 & 0x80) == 0x80 ||
				(controller_status_4 & 0x80) == 0x80) // RIGHT, GG override
			{
				game_loop(5);
			}
			else
			{
				game_loop(0); // check rom header to decide
			}
		}
		else if (menu_pos == 0 && directory_root == 0) // return to root folder
		{
			screen_clear();
			audio_clear();

			screen_flip();
	
			// root directory
			directory_name[0] = '/';
			directory_name[1] = 0;
			directory_name[2] = 0;
			directory_name[3] = 0;
			directory_name[4] = 0;
			directory_name[5] = 0;
			directory_name[6] = 0;
			directory_name[7] = 0;
			directory_name[8] = 0;
			directory_name[9] = 0;
			directory_name[10] = 0;
			directory_name[11] = 0;
			
			directory_root = 1;
		}
		else // must be a file or folder
		{	
			screen_clear();
			audio_clear();

			screen_flip();

			char filename[16];

			for (int i=0; i<16; i++)
			{
				filename[i] = 0;
			}
			
			unsigned char test = 0;

			for (int i=0; i<12; i++)
			{
				filename[i] = list_name[menu_pos*12+i];
				
				if (filename[i] == '.') test = 1;
			}
			
			if (test == 0) // directory
			{
				directory_name[0] = '/';
				
				for (int i=0; i<12; i++)
				{
					directory_name[i+1] = filename[i];
					list_name[i] = filename[i];
				}
				
				directory_root = 0; // no longer root
				
				DelayMS(500);
			}
			else // file
			{
				for (unsigned long i=0; i<SCREEN_XY2; i++)
				{
					screen_buffer[i] = 0x00; // black while burning
				}
				
				controller_enable = 1; // should already be on?

				DelayMS(500);

				screen_flip();

				DelayMS(500);
				
				int wav_flag = 0;
				
				for (int i=0; i<12; i++)
				{
					if (filename[i] == '.' &&
						filename[i+1] == 'W' &&
						filename[i+2] == 'A' &&
						filename[i+3] == 'V') // WAV music
					{
						wav_flag = 1;
					}
				}
				
				if (wav_flag > 0)
				{
					wav_run(directory_name, filename);
					
					DelayMS(1000);

					// soft reset system
					SYSKEY = 0x0; // reset
					SYSKEY = 0xAA996655; // unlock key #1
					SYSKEY = 0x556699AA; // unlock key #2
					RSWRST = 1; // set bit to reset of system
					SYSKEY = 0x0; // re-lock
					RSWRST; // read from register to reset
					while (1) { } // wait until reset occurs
				}
				else
				{
					// Global variables
					FIL file; // File handle for the file we open
					DIR dir; // Directory information for the current directory
					FATFS fso; // File System Object for the file system we are reading from

					unsigned long size = 0;
					unsigned int result;

					//SendString("Initializing disk\n\r\\");
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

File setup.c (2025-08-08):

void __attribute__((optimize("O0"))) Setup()
{
	// turn off analog
	ANSELA = 0x0;
	ANSELB = 0x0;
	ANSELC = 0x0;
	ANSELD = 0x0;
	ANSELE = 0x0;
	ANSELF = 0x0;
	ANSELG = 0x0;
	ANSELH = 0x0;
	//ANSELI = 0x0;
	ANSELJ = 0x0;
	//ANSELK = 0x0;
	
	// make everything output
	TRISA = 0x0;
	TRISB = 0x0;
	TRISC = 0x0;
	TRISD = 0x0;
	TRISE = 0x0;
	TRISF = 0x0;
	TRISG = 0x0;
	TRISH = 0x0;
	//TRISI = 0x0;
	TRISJ = 0x0;
	TRISK = 0x0;
	
	// set all ports to ground
	PORTA = 0x0;
	PORTB = 0x0;
	PORTC = 0x0;
	PORTD = 0x0;
	PORTE = 0x0;
	PORTF = 0x0;
	PORTG = 0x0;
	PORTH = 0x0;
	//PORTI = 0x0;
	PORTJ = 0x0;
	PORTK = 0x0;
	
	// disable all interrupts
	IEC0 = 0x0;
	IEC1 = 0x0;
	IEC2 = 0x0;
	IEC3 = 0x0;
	IEC4 = 0x0;
	IEC5 = 0x0;
	IEC6 = 0x0;
	//IEC7 = 0x0;
	
	// clear all flags
	IFS0 = 0x0;
	IFS1 = 0x0;
	IFS2 = 0x0;
	IFS3 = 0x0;
	IFS4 = 0x0;
	IFS5 = 0x0;
	IFS6 = 0x0;
	//IFS7 = 0x0;
	

	// Set up caching
	unsigned int cp0 = _mfc0(16, 0);
	cp0 &= ~0x07;
	cp0 |= 0b011; // K0 = Cacheable, non-coherent, write-back, write allocate
	//cp0 &= ~0x03;
	//cp0 |= 0x02; // K0 = Uncachable
	_mtc0(16, 0, cp0);  
	
	// change tri-state on pins
	TRISA = 0x0001; // VGA detect
	CNPUA = 0x0001; // VGA detect
	TRISB = 0xFF00; // buttons
	CNPUB = 0xFF00; // buttons
	TRISC = 0x4000; // usb-rx
	CNPUC = 0xC000; // usb-tx/rx
	TRISD = 0xF000; // buttons, ft232rl-rx
	CNPUD = 0xF020; // buttons, ft232rl-tx/rx
	TRISF = 0x013F; // joy-b, usbid
	CNPUF = 0x0004; // usbid
	TRISG = 0x0781; // tf-miso, spi-miso, uart-rx
	CNPUG = 0x0003; // uart-tx/rx
	TRISK = 0x00FF; // menu, joy-select, joy-a
	CNPUK = 0x0080; // menu
	
	// joy-select specifics
	PORTKbits.RK6 = 0; // ground when not floating
	TRISKbits.TRISK6 = 1; // high when floating
	
	controller_mode = 1;

	// set oscillator and timers
	SYSKEY = 0x0; // reset
	SYSKEY = 0xAA996655; // unlock key #1
	SYSKEY = 0x556699AA; // unlock key #2
	
	CFGCONbits.DMAPRI = 1; // DMA does have highest priority (?)
	CFGCONbits.CPUPRI = 0; // CPU does not have highest priority (?)
	CFGCONbits.OCACLK = 1; // use alternate OC/TMR table
	
	PB1DIV = 0x00008001; // divide by 2
	PB2DIV = 0x00008005; // change PB2 clock to 300 / 6 = 50 MHz for SPI and UART
	PB3DIV = 0x00008001; // set OC and TMR clock division by 2
	PB4DIV = 0x00008001; // divide by 2
	PB5DIV = 0x00008003; // divide by 4, used for SQI
	//PB6DIV = 0x00008001; // divide by 2
	PB7DIV = 0x00008000; // CPU clock divide by 1
	SPLLCON = 0x01180001; // use PLL to bring external 24 MHz into 300 MHz
	
	// PRECON - Set up prefetch
	PRECONbits.PFMSECEN = 0; // Flash SEC Interrupt Enable (Do not generate an interrupt when the PFMSEC bit is set)
	PRECONbits.PREFEN = 0b11; // Predictive Prefetch Enable (Enable predictive prefetch for any address)
	PRECONbits.PFMWS = 0b100; // PFM Access Time Defined in Terms of SYSCLK Wait States (Four wait states)
    
	CFGCONbits.USBSSEN = 1; // USB?

	OSCCONbits.SLPEN = 0; // WAIT instruction puts CPU into idle mode
	OSCCONbits.NOSC = 0x1; // switch to SPLL
	OSCCONbits.OSWEN = 1; // enable the switch
	SYSKEY = 0x0; // re-lock
	
	while (OSCCONbits.OSWEN != 0) { } // wait for clock switch to complete

	// set PPS
	SYSKEY = 0x0; // reset
	SYSKEY = 0xAA996655; // unlock key #1
	SYSKEY = 0x556699AA; // unlock key #2
	CFGCONbits.IOLOCK = 0; // PPS is unlocked
	RPD2R = 0xB; // OC3 on pin RPD2 (h-sync)
	RPD3R = 0xC; // OC7 on pin RPD3 (v-sync)
	SDI1R = 0x1; // SDI1 on pin RPG8 (miso)
	RPD10R = 0x5; // SDO1 on pin RPD7 (mosi)
	// SCK1 on RD1 (sclk)
	// CS1 on RD9 (cs)
	//U2RXR = 0x4; // U2RX on pin RPD4 (uart rx)
	RPD5R = 0x2; // U2TX on pin RPD5 (uart tx)
	CFGCONbits.IOLOCK = 1; // PPS is locked
	SYSKEY = 0x0; // re-lock
	 
	
	

	// set up UART here
	U2BRG = 0x0145; // 50 MHz to 9600 baud = 50000000/(16*9600)-1 = 324.52 = 0x0145
	
	U2MODEbits.STSEL = 0; // 1-Stop bit
	U2MODEbits.PDSEL = 0; // No Parity, 8-Data bits
	U2MODEbits.BRGH = 0; // Standard-Speed mode
	U2MODEbits.ABAUD = 0; // Auto-Baud disabled
	
	//U2MODEbits.URXINV = 1; // reverse polarity
	//U2STAbits.UTXINV = 1; // reverse polarity
	
	U2MODEbits.UEN = 0x0; // just use TX and RX
	
	U2STAbits.UTXISEL = 0x0; // Interrupt after one TX character is transmitted
	U2STAbits.URXISEL = 0x0; // interrupt after one RX character is received
	
	//U2STAbits.URXEN = 1; // enable RX
	U2STAbits.UTXEN = 1; // enable TX
	
	IPC36bits.U2RXIP = 0x4; // U2RX interrupt priority level 4
	IPC36bits.U2RXIS = 0x0; // U2RX interrupt sub-priority level 0
	//IPC39bits.U2EIP = 0x4; // U2E interrupt priority level 4
	//IPC39bits.U2EIS = 0x1; // U2E interrupt sub-priority level 1
	IFS4bits.U2RXIF = 0;  // clear interrupt flag
	//IEC4bits.U2RXIE = 1; // U2RX interrupt on (set priority here?)
	IEC4bits.U2RXIE = 0; // U2RX interrupt off
	
	U2MODEbits.ON = 1; // turn UART on
	
	
	// set up interrupt-on-change for menu button
	CNCONKbits.ON = 1; // turn on interrupt-on-change
	CNCONKbits.EDGEDETECT = 1; // edge detect, not mismatch
	CNNEK = 0x0080; // negative edge on RK7
	CNFK = 0x0000; // clear flags
	
	IPC31bits.CNKIP = 0x1; // interrupt priority 1
	IPC31bits.CNKIS = 0x0; // interrupt sub-priority 0
	IFS3bits.CNKIF = 0;  // clear interrupt flag
	IEC3bits.CNKIE = 1; // enable interrupts
	
	
	// set up SPI here
	PORTDbits.RD9 = 1; // CS is high
	PORTDbits.RD10 = 1; // MOSI is high
	PORTDbits.RD1 = 0; // CLK is low	
	
	SPI1CONbits.ON = 0; // turn SPI module off
	SPI1CON2 = 0; // disable audio, etc.
	SPI1CONbits.DISSDI = 0; // SDI controlled by module
	SPI1CONbits.DISSDO = 0; // SDO controlled by module
	SPI1CONbits.MODE16 = 0x0; // 8-bit mode
	SPI1CONbits.MSTEN = 1; // host mode
	SPI1CONbits.MSSEN = 0; // client SS disabled
	SPI1CONbits.SSEN = 0; // client SS disabled
	SPI1CONbits.SMP = 0; // input sampled in middle of output time
	SPI1CONbits.CKE = 1; // output changes on idle-to-active clock
	SPI1CONbits.CKP = 0; // clock is idle low, active high
	SPI1CONbits.ON = 1; // turn SPI module on
	
	SPI1BUF = 0xFFFF; // dummy write
	while (SPI1STATbits.SPIRBF == 0) { } // wait
	sdcard_block[0] = SPI1BUF; // dummy read
	
	// set shadow register priorities???
	PRISS = 0x76543210; //0x76543210;
	
	// enable multi-vector interrupts???
	INTCONSET = _INTCON_MVEC_MASK;
	
	// IDK, just turn on interrupts globally???
	__builtin_enable_interrupts();
	
	
	// turn LED off by default
	PORTDbits.RD7 = 1;
	
	// clear usb buffers
	for (unsigned int i=0; i<256; i++)
	{
		usb_state_array[i] = 0x00;
		usb_cursor_x[i] = 0x0000;
		usb_cursor_y[i] = 0x0000;
		
	}

	// timer 8 for audio
	T8CON = 0x0000; // reset
	T8CON = 0x0000; // prescale of 1:1, 16-bit
	TMR8 = 0x0000; // zero out counter
	PR8 = 0x6F9C; // approx three scanlines (minus one)
	
	// timer 9 for frame timing
	T9CON = 0x0000; // reset
	T9CON = 0x0070; // prescale of 1:256, 16-bit
	TMR9 = 0x0000; // zero out counter
	PR9 = 0x2625;  // one whole frame (minus one)
	
	IPC9bits.T8IP = 0x3; // interrupt priority 3
	IPC9bits.T8IS = 0x0; // interrupt sub-priority 0
	IFS1bits.T8IF = 0; // T8 clear flag
	IEC1bits.T8IE = 1; // T8 interrupt on
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
